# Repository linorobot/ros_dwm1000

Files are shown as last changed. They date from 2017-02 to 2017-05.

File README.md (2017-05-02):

# ros_dwm1000

ROS Indoor/Outdoor Positioning System based on Decawave's DWM1000 Ultra Wide Band transceivers.
The whole system was tested indoors with 3 anchors and 1 tag. Technically this should work outdoors as well.

IMAGE ALT TEXT (https://www.youtube.com/embed/BuBnmrkJ9BY "ROS Indoor Localization using Decawave's UWB Transceivers ")

### Hardware
Both anchors and tags use the same circuit board. The board houses the UWB transceiver, an Arduino Pro Mini 3.3V and a built-in USB
Male so you can plug it straight to a power bank and deploy the anchors remotely.

1. If you wish to fabricate the PCB, the Gerber files are included /hardware/pcb/fabricate.
Seeedstudio's DRU for 2-layer board was used to verify the design.

2. The DWM1000 Arduino library  uses random address for the anchors and doesn't support arbitrary addresses.
You need to edit https://github.com/grassjelly/ros_dwm1000/blob/master/hardware/firmware/anchor/lib/DW1000/DW1000Ranging.cpp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 every time you upload the
anchor codes to have unique address per anchor from:

    ```c++
    _currentShortAddress[0] = random(0, 256);
    _currentShortAddress[1] = random(0, 256);
    ```
    to the address you want (ie. address: '01'):

    ```c++
    _currentShortAddress[0] = 1;
    _currentShortAddress[1] = 0;
    ```

### Installation
1. Install dependencies

    ```sh
    $ pip install localization
    $ pip install scipy
    $ pip install shapely
    ```

2. Install map_server

    ```sh
    $ sudo apt-get install ros-indigo-map-server
    ```

3. Build the package

    ```sh
    $ cd ~/catkin_ws
    $ catkin_make
    ```

### Defining TF
1. You need to define the transforms from map to each anchor's frame. You can run map_server and load your map to identify
the exact points you want your anchors placed. Open RVIZ and click on the location of each anchor by using "Publish Points".

2. Once you get the exact location of each anchor, add the transforms in /launch/tf.launch file. Take note that the frame_id of
each anchor must be the same as the address defined in Arduino (_currentShortAddress[]).

### Usage
1. Run localize.launch:			

    ```sh
    $ roslaunch ros_dwm1000 localize.launch
    ```

### Parameters
##### serial_port(default: '/dev/ttyUSB0')
Tag's serial port.

##### frame_id(default: 'uwb_tag')
Tag's frame_id when transform's published from map to tag.

##### req_anchor(default: 3)
The mininum number of anchors the system must find before performing trilateration between anchors. Increase this if you want to improve the accuracy. This can be tweaked down to a minimum of 2 anchors. Each tag can only support up to 4 anchors now.

##### min_range(default: 0.5)
The minimum probable distance from an anchor to a tag to prevent false reading. For example, if your anchor is hanging 1 m away from
the floor, it makes sense to put 1 meter as minimum range since there's no way it will range less than 1 meter.

##### max_range(default: 10.0)
The maximum probable distance from an anchor to a tag to prevent false reading. For example, if your anchors are placed in 8 meter x 8 meter room,
you can set the max_range less than or equal the hypotenuse of the room since ranges won't get any longer than that.

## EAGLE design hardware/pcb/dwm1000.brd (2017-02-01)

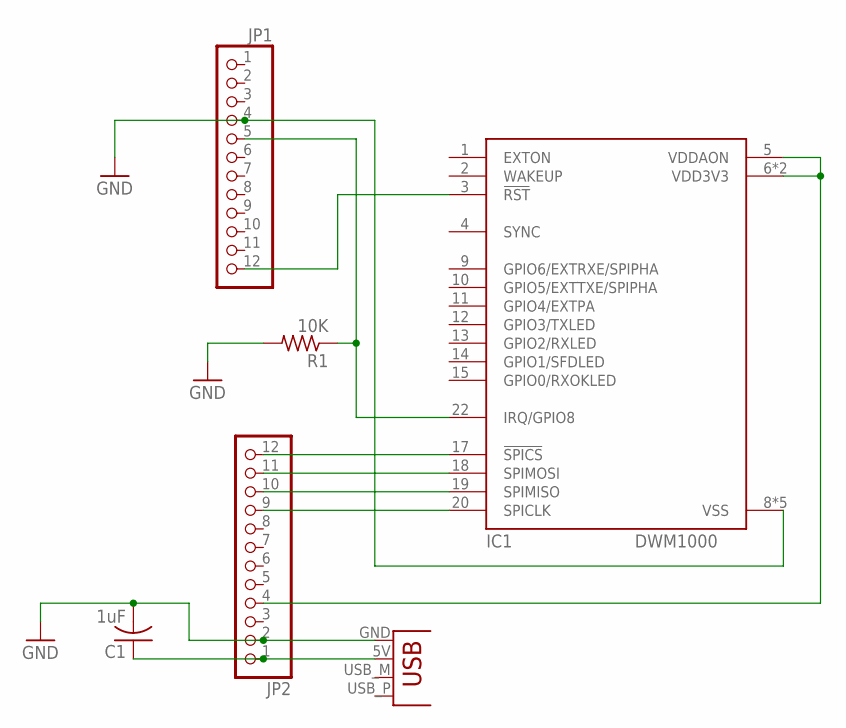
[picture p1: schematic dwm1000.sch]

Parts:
C1: 1uF; C025-024X044
IC1: DWM1000
JP1, JP2: PINHD-1X12; 1X12
JP3: USBPCB; USB-A-PCB
R1: 10K; 0207/7

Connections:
GND: C1.2, IC1.8 (VSS), IC1.16 (VSS), IC1.21 (VSS), IC1.23 (VSS), IC1.24 (VSS), JP1.4, JP2.2, JP3.GND, R1.2
unnamed: IC1.3 (!RST), JP1.12
unnamed: IC1.17 (!SPICS), JP2.12
unnamed: IC1.18 (SPIMOSI), JP2.11
unnamed: IC1.20 (SPICLK), JP2.9
unnamed: IC1.19 (SPIMISO), JP2.10
unnamed: IC1.22 (IRQ/GPIO8), JP1.5, R1.1
unnamed: C1.1, JP2.1, JP3.5V (VBUS)
unnamed: IC1.5 (VDDAON), IC1.6 (VDD3V3), IC1.7 (VDD3V3), JP2.4

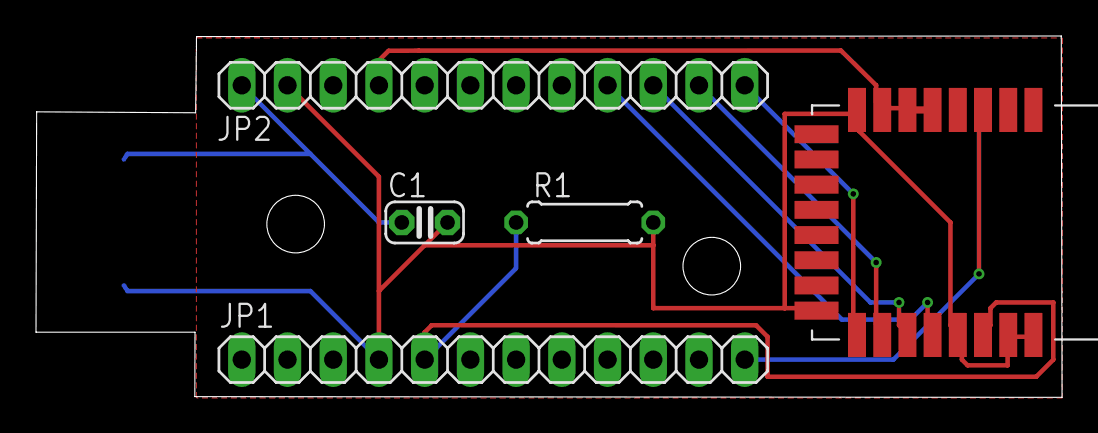
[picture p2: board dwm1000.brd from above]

Board: 2 copper layers, 57.0 x 20.1 mm, 6 parts (1 on the bottom side), 9 nets.

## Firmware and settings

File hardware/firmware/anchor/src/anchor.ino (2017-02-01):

#include <SPI.h>
#include "DW1000Ranging.h"
#include "DW1000Device.h"

// connection pins
const uint8_t PIN_RST = 9; // reset pin
const uint8_t PIN_IRQ = 2; // irq pin
const uint8_t PIN_SS = SS; // spi select pin

void setup() {
  Serial.begin(115200);
  delay(1000);

  DW1000Ranging.initCommunication(PIN_RST, PIN_SS, PIN_IRQ);
  DW1000Ranging.attachNewRange(newRange);
  DW1000Ranging.attachBlinkDevice(newBlink);
  DW1000Ranging.attachInactiveDevice(inactiveDevice);
  DW1000Ranging.useRangeFilter(true);

  DW1000Ranging.startAsAnchor("02:00:5B:D5:A9:9A:E2:9C", DW1000.MODE_LONGDATA_RANGE_ACCURACY);
}

void loop() {
  DW1000Ranging.loop();
}

void newRange() {

}

void newBlink(DW1000Device* device) {

}

void inactiveDevice(DW1000Device* device) {

}

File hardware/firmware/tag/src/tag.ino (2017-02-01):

#include <SPI.h>
#include "DW1000Ranging.h"
#include "DW1000Device.h"
// #include "sender.h"

// Sender sender;
#define SENSOR_OFFSET 0.4
// connection pins
const uint8_t PIN_RST = 9; // reset pin
const uint8_t PIN_IRQ = 2; // irq pin
const uint8_t PIN_SS = SS; // spi select pin

void setup() {
  Serial.begin(115200);
  delay(1000);
  DW1000Ranging.initCommunication(PIN_RST, PIN_SS, PIN_IRQ);
  DW1000Ranging.attachNewRange(newRange);
  DW1000Ranging.attachNewDevice(newDevice);
  DW1000Ranging.attachInactiveDevice(inactiveDevice);
  DW1000Ranging.useRangeFilter(true);

  //start the hardware as tag
  DW1000Ranging.startAsTag("01:00:5B:D5:A9:9A:E2:9C",DW1000.MODE_LONGDATA_RANGE_ACCURACY);
}

void loop() {
  DW1000Ranging.loop();
  //keep waiting for command from ROS node.
  // sender.loop();
}

void newRange() {
  //insert to the message
  // sender.newDevice(DW1000Ranging.getDistantDevice()->getShortAddress(),
  //                  DW1000Ranging.getDistantDevice()->getRange() - SENSOR_OFFSET);
  Serial.print('$');
  Serial.print(DW1000Ranging.getDistantDevice()->getShortAddress(), HEX);
  Serial.print(',');
  Serial.println(DW1000Ranging.getDistantDevice()->getRange());

}

void newDevice(DW1000Device* device) {
  //add device from total no of devices around
  // sender.addDevice();
}

void inactiveDevice(DW1000Device* device) {
  //delete device from total no of devices around
  // sender.deleteDevice();

}

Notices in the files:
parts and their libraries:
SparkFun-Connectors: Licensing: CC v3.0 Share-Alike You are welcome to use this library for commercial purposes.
